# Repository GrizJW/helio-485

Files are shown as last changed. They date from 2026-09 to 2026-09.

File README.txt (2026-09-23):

Helio-485 Rev A — KiCad layout

Open helio-485.kicad_pcb. KiCad 10 (file version 20260206).

Board: 140 x 218 mm, 2 layer, 1.6 mm, 2 oz. No cell holders.
J5 is the 2S pouch (PACK−, PACK+). J6 is the balance lead (PACK−, midpoint, PACK+). Charge current is
set to 2 A, which is the TP5100 limit. U10 is an LM393 low-voltage
disconnect: it forces the 12 V boost off below 6.4 V on the pack.
J7 is the Ethernet jack. U11 is a W5500. The C5 has no MAC.

What is already done
- Official KiCad footprints for the holders, USB-C (HRO TYPE-C-31-M-12),
  Phoenix 5.08 mm terminals, SOT-23, SOT-23-6, SOIC-8, QFN-16, TO-252,
  TO-92, and the passives.
- ESP32-C5-WROOM-1 land from the Espressif pattern: 1.27 mm pitch,
  1.5 x 0.9 mm pads, row centers at ±8.0 mm, pad column span 16.51 mm,
  antenna at +Y. Pin 1 is the antenna-end pad on the left, marked with a dot.
- TPS61088 RHL0020A land from TI drawing 4219071. Pin 1 is the bottom-left
  pad. The exposed pad is pin 21 (PGND).
- Nets on every placed pad.
- J5 and J6 are the pack. PACK− is a 2 mm track into the sense resistor.
  PACK+ is a 2 mm track into F1. The midpoint is on J6 pin 2.
- Back copper is a GND zone. Press B to fill it.
- Antenna keepout is a rule area on both layers at the top-right. No copper.

What you still route
Everything else is a ratsnest. Do that in pcbnew, then run DRC.
Do not run Update PCB from Schematic. There is no schematic in this
project; the nets live on the board.

Check before you fab
- S-8252 pin numbers are the SOT-23-6 table: 1 DO, 2 CO, 3 VM, 4 VC,
  5 VDD, 6 VSS. VDD is the top of the stack.
- TP5100 pin numbers follow the datasheet grouping used on the rev A
  sheet (VIN on 1/4/5/16, LX on 2/3, BAT on 9). Confirm against the reel.
- AO3401A is G/S/D = pins 1/2/3. AOD510 is G/D/S = 1/2/3, tab is drain.
- USB-C (J4, HRO TYPE-C-31-M-12) is on the left edge, plug facing out.
  D+ / D− go through 22 Ω (Rdp, Rdm) to module pins 14 and 13
  (GPIO14 USB D+, GPIO13 USB D−). CC1 and CC2 are 5.1 kΩ to GND.
  D3 (B5819W, SOD-123 pin 1 = cathode) ORs VBUS onto VSYS so the
  3.3 V buck runs from the laptop when the pack is out. USB does not
  charge the cells. Full-speed only; the pair is not 90 Ω.
- USB-C programs the ESP32. J2 is the GEM2 supply: pin 1 yellow, pin 2 purple.
  J3 is RS-485 Modbus. Pin 1 is A (GEM2 pink), pin 2 is B (GEM2 green),
  pin 3 is ground. U6 is a THVD1400. GPIO5 drives D, GPIO4 reads R,
  GPIO6 is DE and /RE tied together. Ra and Rb are 10 ohm between the
  chip and the bus. D2 is an SM712 in SOT-23. Pins 1 and 2 are the
  same 12 V line clamps; this layout uses pin 1 as B and pin 2 as A so
  the two traces do not cross. Pin 3 is ground, with a via into the
  ground plane. SJ1 ships open, so the 120 ohm is not across the pair
  unless this node is an end of the cable.
  The meter wants external power for Modbus. That power is J2.
- Panel on J1: 30 W, Vmp about 16 V, Voc at or below 17 V. A normal
  12 V panel with Voc near 21 V will kill the TP5100. 2 A fills a
  10 Ah pack in about 6 hours of sun, not 4. That is the chip limit.
- U10 trips at 6.4 V on the pack and holds the 12 V rail off until
  the pack is about 0.3 V higher. GPIO23 cannot override it.
- Ethernet is SPI, not RMII. GPIO0 low enables Q5. Confirm the
  HR911105A land against the jack you buy before Gerbers.

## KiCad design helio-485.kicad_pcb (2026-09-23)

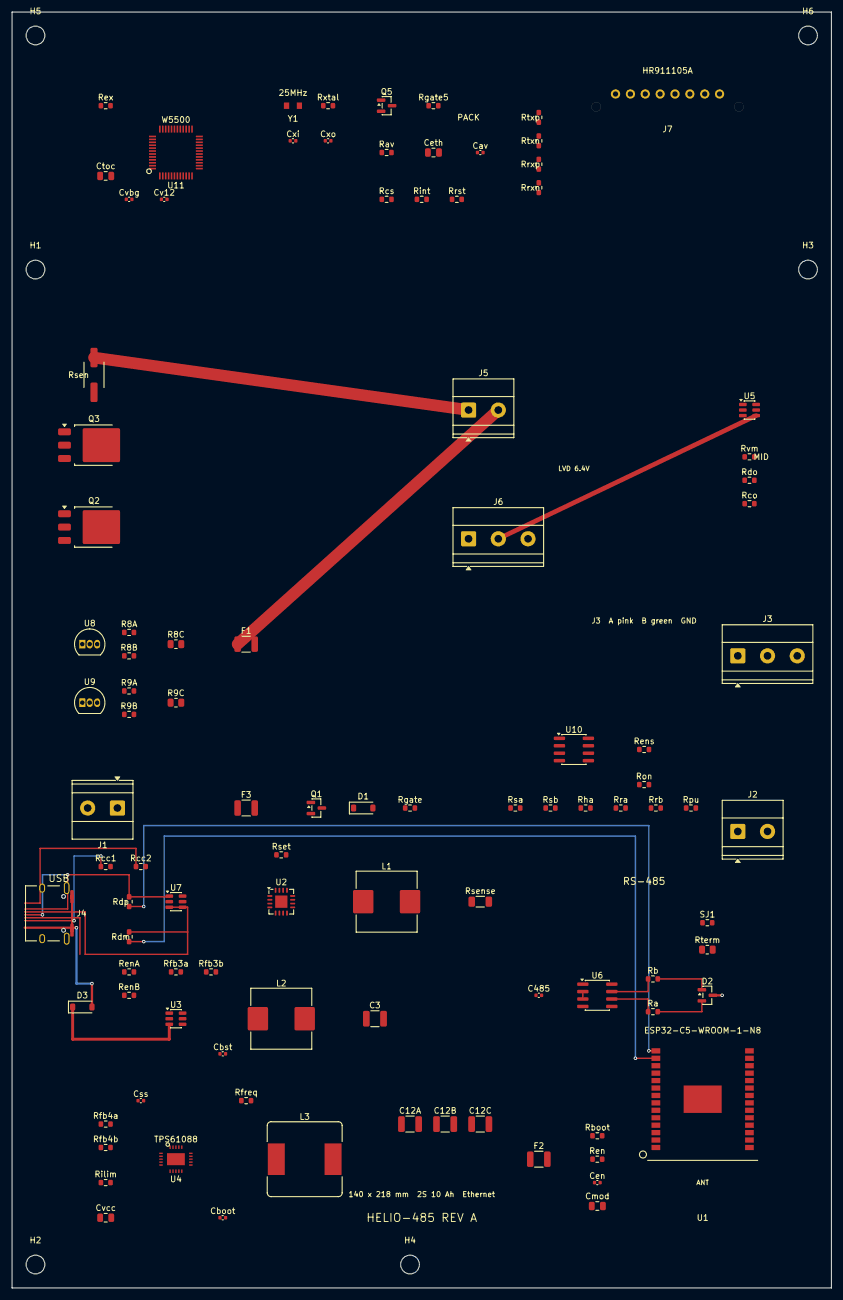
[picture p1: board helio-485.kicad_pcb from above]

Board: 2 copper layers, 140.0 x 218.0 mm, 106 parts (0 on the bottom side), 80 nets.

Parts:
C3, C12A, C12B, C12C: 22uF; C_1210_3225Metric
C485: 100n; C_0402_1005Metric
Cav: 100n; C_0402_1005Metric
Cboot: 100n; C_0402_1005Metric
Cbst: 100n; C_0402_1005Metric
Cen: 1uF; C_0402_1005Metric
Ceth: 10uF; C_0805_2012Metric
Cmod: 10uF; C_0805_2012Metric
Css: 47n; C_0402_1005Metric
Ctoc: 4.7u; C_0805_2012Metric
Cv12: 10n; C_0402_1005Metric
Cvbg: 10n; C_0402_1005Metric
Cvcc: 1uF; C_0805_2012Metric
Cxi: 18p; C_0402_1005Metric
Cxo: 18p; C_0402_1005Metric
D1: BZT52C10; D_SOD-123
D2: SM712; SOT-23
D3: B5819W; D_SOD-123
F1: PTC-6A; R_1210_3225Metric
F2: PTC-2.5A; R_1210_3225Metric
F3: PTC-2A; R_1210_3225Metric
H1, H2, H3, H4, H5, H6: M3; MountingHole_3.2mm_M3
J1: PV; TerminalBlock_Phoenix_MKDS-1,5-2-5.08_1x02_P5.08mm_Horizont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
J2: 12V; TerminalBlock_Phoenix_MKDS-1,5-2-5.08_1x02_P5.08mm_Horizont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
J3: Modbus; TerminalBlock_Phoenix_MKDS-1,5-3-5.08_1x03_P5.08mm_Horizont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
J4: USB-C; USB_C_Receptacle_HRO_TYPE-C-31-M-12
J5: PACK; TerminalBlock_Phoenix_MKDS-1,5-2-5.08_1x02_P5.08mm_Horizont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
J6: BAL; TerminalBlock_Phoenix_MKDS-1,5-3-5.08_1x03_P5.08mm_Horizont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
J7: HR911105A; RJ45-Magjack
L1: 22uH; L_Wuerth_HCI-1040
L2: 4.7uH; L_Wuerth_HCI-1040
L3: 2.2uH; L_Bourns_SRR1260
Q1, Q5: AO3401A; SOT-23
Q2, Q3: AOD510; TO-252-3_TabPin2
R8A, R9A: 6.81k; R_0603_1608Metric
R8B, R9B: 10.0k; R_0603_1608Metric
R8C, R9C: 47; R_0805_2012Metric
Ra: 10; R_0603_1608Metric
Rav: 3.3; R_0603_1608Metric
Rb: 10; R_0603_1608Metric
Rboot: 10k; R_0603_1608Metric
Rcc1, Rcc2: 5.1k; R_0603_1608Metric
Rco: 100; R_0603_1608Metric
Rcs: 4.7k; R_0603_1608Metric
Rdm: 22; R_0603_1608Metric
Rdo: 100; R_0603_1608Metric
Rdp: 22; R_0603_1608Metric
Ren: 10k; R_0603_1608Metric
RenA: 100k; R_0603_1608Metric
RenB: 150k; R_0603_1608Metric
Rens: 10k; R_0603_1608Metric
Rex: 12.4k; R_0603_1608Metric
Rfb3a: 33.0k; R_0603_1608Metric
Rfb3b: 10.0k; R_0603_1608Metric
Rfb4a: 422k; R_0603_1608Metric
Rfb4b: 47.0k; R_0603_1608Metric
Rfreq: 255k; R_0603_1608Metric
Rgate, Rgate5: 100k; R_0603_1608Metric
Rha: 470k; R_0603_1608Metric
Rilim: 140k; R_0603_1608Metric
Rint: 4.7k; R_0603_1608Metric
Ron: 1k; R_0603_1608Metric
Rpu: 100k; R_0603_1608Metric
Rra: 17.4k; R_0603_1608Metric
Rrb: 10.0k; R_0603_1608Metric
Rrst: 4.7k; R_0603_1608Metric
Rrxn: 49.9; R_0603_1608Metric
Rrxp: 49.9; R_0603_1608Metric
Rsa: 43.2k; R_0603_1608Metric
Rsb: 10.0k; R_0603_1608Metric
Rsen: 0.010; R_2512_6332Metric
Rsense: 0.050; R_1206_3216Metric
Rset: 0; R_0603_1608Metric
Rterm: 120; R_0805_2012Metric
Rtxn: 49.9; R_0603_1608Metric
Rtxp: 49.9; R_0603_1608Metric
Rvm: 330; R_0603_1608Metric
Rxtal: 1M; R_0603_1608Metric
SJ1: OPEN; R_0603_1608Metric
U1: ESP32-C5-WROOM-1-N8; ESP32-C5-WROOM-1
U2: TP5100; QFN-16-1EP_4x4mm_P0.65mm_EP2.1x2.1mm
U3: TPS562208; SOT-23-6
U4: TPS61088; TPS61088-RHL
U5: S-8252; SOT-23-6
U6: THVD1400; SOIC-8_3.9x4.9mm_P1.27mm
U7: USBLC6-2; SOT-23-6
U8, U9: TL431A; TO-92_Inline
U10: LM393; SOIC-8_3.9x4.9mm_P1.27mm
U11: W5500
Y1: 25MHz; Crystal-3225

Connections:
12V_OUT: F2.2, J2.1
+3V3: C3.1, C485.1, Cmod.1, L2.2, Q5.2, Rboot.1, Ren.1, Rfb3a.1, Rgate5.2, Rpu.1, Rra.1, U1.2, U6.8, U10.8
+3V3_LDO: Cvcc.1, U4.1
+12V: C12A.1, C12B.1, C12C.1, F2.1, Rfb4a.1, U4.14, U4.15, U4.16
A: D2.2, J3.1, Ra.2, Rterm.1
AVDD: Cav.1, Rav.2, U11.4, U11.8, U11.11, U11.15, U11.17, U11.21
A_DRV: Ra.1, U6.6
B: D2.1, J3.2, Rb.2, SJ1.2
BOOT: Cboot.1, Rboot.2, U1.27, U4.8
BST3: Cbst.1, U3.6
B_DRV: Rb.1, U6.7
CATH1: R8A.1, R8C.2, U8.3
CATH2: R9A.1, R9C.2, U9.3
CC1: J4.A5, Rcc1.1
CC2: J4.B5, Rcc2.1
CO: Q2.1, Rco.1, Rco.2, U5.2
DO: Q3.1, Rdo.1, Rdo.2, U5.1
EN3: RenA.2, RenB.1, U3.5
EN12: Rens.2, Rha.1, Rpu.2, U4.2, U10.1
EN12_MCU: Rens.1, U1.21
EN_MCU: Cen.1, Ren.2, U1.3
ETH_3V3: Ceth.1, Q5.3, Rav.1, Rcs.1, Rint.1, Rrst.1, U11.28, U11.43, U11.44, U11.45
ETH_CS: Rcs.2, U1.11, U11.32
ETH_GATE: Q5.1, Rgate5.1, Ron.2
ETH_INT: Rint.2, U1.23, U11.36
ETH_MISO: U1.5, U11.34
ETH_MOSI: U1.12, U11.35
ETH_ON: Ron.1, U1.6
ETH_RST: Rrst.2, U1.26, U11.37
ETH_RXN: Rrxn.1, U11.5
ETH_RXN_J: J7.6, Rrxn.2
ETH_RXP: Rrxp.1, U11.6
ETH_RXP_J: J7.3, Rrxp.2
ETH_SCLK: U1.4, U11.33
ETH_TXN: Rtxn.1, U11.1
ETH_TXN_J: J7.2, Rtxn.2
ETH_TXP: Rtxp.1, U11.2
ETH_TXP_J: J7.1, Rtxp.2
EXRES: Rex.1, U11.10
FB3: Rfb3a.2, Rfb3b.1, U3.4
FB12: Rfb4a.2, Rfb4b.1, U4.17
FETSRC: Q2.3, Q3.3
FSW: Rfreq.1, U4.3
GATE: D1.1, Q1.1, Rgate.1
GND: C3.2, C12A.2, C12B.2, C12C.2, C485.2, Cav.2, Cen.2, Ceth.2, Cmod.2, Css.2, Ctoc.2, Cv12.2, Cvbg.2, Cvcc.2, Cxi.2, Cxo.2, D2.3, J1.2, J2.2, J3.3, J4.A1, J4.A12, J4.B1, J4.B12, J4.SH, J7.S1, J7.S2, Rcc1.2, Rcc2.2, RenB.2, Rex.2, Rfb3b.2, Rfb4b.2, Rgate.2, Rilim.2, Rrb.2, Rsb.2, U1.1, U1.28, U1.29, U2.7, U2.17, U3.1, U4.11, U4.12, U4.13, U4.20, U4.21, U6.5, U7.2, U10.4, U10.5, U10.6, U10.7, U11.3, U11.9, U11.14, U11.16, U11.19, U11.29, U11.48
ILIM: Rilim.1, U4.19
LVD_REF: Rra.2, Rrb.1, U10.2
LVD_SNS: Rha.2, Rsa.2, Rsb.1, U10.3
LX: L1.1, U2.2, U2.3
MID: J6.2, R8C.1, R9B.2, U5.4, U9.2
PACK+: F1.1, J5.2, J6.3, R9C.1, Rsense.2, U2.9, U5.5
PACK-: J5.1, J6.1, R8B.2, Rsen.1, U5.6, U8.2
PACKN_OUT: Q2.2, Rvm.2
PV: F3.1, J1.1
PVF: F3.2, Q1.3
REF1: R8A.2, R8B.1, U8.1
REF2: R9A.2, R9B.1, U9.1
RS485_DE: U1.8, U6.2, U6.3
RS485_RX: U1.17, U6.1
RS485_TX: U1.16, U6.4
SENSE: Q3.2, Rsen.2
SS: Css.1, U4.10
SW3: Cbst.2, L2.1, U3.2
SW4: Cboot.2, L3.2, Rfreq.2, U4.4, U4.5, U4.6, U4.7
TERM: Rterm.2, SJ1.1
TOCAP: Ctoc.1, U11.20
USB_DM: Rdm.2, U1.13
USB_DM_C: J4.A7, J4.B7, Rdm.1, U7.3, U7.4
USB_DP: Rdp.2, U1.14
USB_DP_C: J4.A6, J4.B6, Rdp.1, U7.1, U7.6
USB_VBUS: D3.2, J4.A4, J4.A9, J4.B4, J4.B9, U7.5
V12O: Cv12.1, U11.22
VBG: Cvbg.1, U11.18
VIN_CHG: D1.2, Q1.2, U2.1, U2.4, U2.5, U2.16
VM: Rvm.1, U5.3
VREG: Rset.1, Rset.2, U2.10, U2.13
VS: L1.2, Rsense.1, U2.8
VSYS: D3.1, F1.2, L3.1, RenA.1, Rsa.1, U3.3, U4.9
XTAL_XI: Cxi.1, Rxtal.1, U11.30, Y1.1
XTAL_XO: Cxo.1, Rxtal.2, U11.31, Y1.2

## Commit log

2026-09-23 Add Helio-485 KiCad board
    Placed and netlisted 140x178 mm board: ESP32-C5, 2S 18650, solar charger, 3.3 V rail, 12 V 2 A boost, RS-485.
    [helio-485.kicad_pcb]
2026-09-23 Fix KiCad load error on heatsink pads
    Pad fab properties were written as (property pad_prop_heatsink (uuid ...)).
    KiCad ends that property at the first closing paren, so (layers ...) was parsed as a footprint token.
    [helio-485.kicad_pcb]
2026-09-23 Put USB-C on the left edge for programming
    J4 faces off the board. D+ and D- reach ESP32-C5 pins 14 and 13 through 22 ohm resistors. D3 ORs VBUS onto the 3.3 V buck so the laptop can flash the module with the pack out.
    [helio-485.kicad_pcb]
2026-09-23 Size the pack for a GloTech GEM2 on 3500 mAh cells
    Six 18650s in 2S3P. The meter is 80-90 mA at 12 V, so this is about two days. J2 is yellow/purple and J3 is the meter's RS-485 pair.
    [helio-485.kicad_pcb]
2026-09-23 Cap the pack at two 3500 mAh cells
    Three 3500 mAh cells cannot run a GEM2 for 48 hours, and the charger and protector are 2-cell parts. Board is back to 140 x 178 mm.
    [helio-485.kicad_pcb]
2026-09-23 Replace the 18650 holders with a 2S pouch connector
    Two 10 Ah flat cells cover about 43 hours at 90 mA. J5 is the pack and J6 is the balance lead.
    [helio-485.kicad_pcb]
2026-09-23 Add a pack LVD and size the solar input for 2 A
    The TP5100 cannot fill 10 Ah in 4 hours. Charge current is now its 2 A limit, and the boost is forced off below 6.4 V.
    [helio-485.kicad_pcb]
2026-09-23 Add W5500 Ethernet on the bottom edge
    The ESP32-C5 has no MAC, so the jack is a W5500 on SPI. GPIO0 turns the PHY rail off when the pack has to last.
    [helio-485.kicad_pcb]
2026-09-23 Update the board to the KiCad 10 file format.
    File version 20260206. Nets are stored by name.
    [helio-485.kicad_pcb]
